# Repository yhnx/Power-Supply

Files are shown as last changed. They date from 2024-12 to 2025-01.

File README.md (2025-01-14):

# Power-Supply
A repository containing the Schematics, Presentations and 3D models which were used to design a Variable Voltage Power Supply which was built for the module EN 2091 Laboratory Practice and Projects

### **Documentation**
- [`Project_Proposal.pdf`](./DM_27/Project_Proposal.pdf): Formal proposal document for the project.
- [`Presentation_27.pptx`](./DM_27/Presentation_27.pptx): Project presentation slides.
- [`Project_report_27.pdf`](./DM_27/Project_report_27.pdf): Comprehensive project report.
  
### **DM_27**
Contains project-related files and resources.

- **Datasheets/**
  - [`BR5010 rectifier.pdf`](./DM_27/Datasheets/BR5010%20rectifier.pdf): Datasheet for the BR5010 bridge rectifier.
  - [`LD1085 (1).pdf`](./DM_27/Datasheets/LD1085%20(1).pdf): Datasheet for the LD1085 low-dropout regulator.
  - [`The TIP142G is a Darlington transistor.pdf`](./DM_27/Datasheets/The%20TIP142G%20is%20a%20Darlington%20transistor.pdf): Datasheet for the TIP142G transistor.
  - [`lm338 adjustable regulator.pdf`](./DM_27/Datasheets/lm338%20adjustable%20regulator.pdf): Datasheet for the LM338 adjustable voltage regulator.
  - [`power transformer datasheet.pdf`](./DM_27/Datasheets/power%20transformer%20datasheet.pdf): Datasheet for the power transformer used.
  - [`voltage regulator.pdf`](./DM_27/Datasheets/voltage%20regulator.pdf): Additional voltage regulator datasheet.

- **Enclosure/**
  - [`Assem1.SLDASM`](./DM_27/Enclosure/Assem1.SLDASM): SolidWorks assembly file for the enclosure.
  - [`Part1.SLDPRT`](./DM_27/Enclosure/Part1.SLDPRT): SolidWorks part file for the enclosure.
  - [`TOP.SLDPRT`](./DM_27/Enclosure/TOP.SLDPRT): SolidWorks part file for the enclosure.
  - [`bottom part.DXF`](./DM_27/Enclosure/bottom%20part.DXF): DXF file for the bottom part of the enclosure.
  - [`top part.DXF`](./DM_27/Enclosure/top%20part.DXF): DXF file for the top part of the enclosure.

- [`BOM_Linear_Power_Supply.xlsx`](./DM_27/BOM_Linear_Power_Supply.xlsx): Bill of Materials for the power supply project.
- [`Gerber files.zip`](./DM_27/Gerber%20files.zip): Gerber files for PCB manufacturing.
- [`Linear power supply Schematic.asc`](./DM_27/Linear%20power%20supply%20Schematic.asc): LTspice schematic file for the linear power supply.
- [`testing.asc`](./DM_27/testing.asc): LTspice testing simulation file.

---

## Usage Instructions

1. **View Datasheets**: Explore the `Datasheets/` folder for component specifications.
2. **Enclosure Design**: Open SolidWorks or a DXF viewer to inspect the enclosure files in the `Enclosure/` folder.
3. **PCB Manufacturing**: Use the `Gerber files.zip` for PCB fabrication.
4. **Simulation**: Open `.asc` files in LTspice for schematic simulation and analysis.
5. **Documentation**: Refer to the `Presentation_27.pptx`, `Project_Proposal.pdf`, and `Project_report_27.pdf` for project insights.

---

### The team behind 
* Yehen Asuramuni ([@yhnx](https://github.com/yhnx))
* Sineth Jayawardena ([@SinethS](https://github.com/sineths))
* Oshada Nimatha ([@Oshadha-Nimantha](https://github.com/Oshadha-Nimantha))
* Agrajith Weeragoda

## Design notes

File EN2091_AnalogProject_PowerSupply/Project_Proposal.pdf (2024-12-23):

# Proposal: Variable Voltage Linear Power Supply

Team Wave Formers

August 25, 2024

Index No. | Name
220046R | Asuramuni S. Y.
220280D | Jayawardena H.D.S.S
220429U | Nimantha K.L.W.O.
220692R | Weragoda W.A.A.P.

## Introduction

This proposal presents the design and implementation of a variable voltage linear power supply. The power supply is designed to provide a regulated DC output voltage ranging from 2V to 20V, with a maximum current output of 2.5A. A low-dropout (LDO) voltage regulator is employed to ensure stable operation and efficient power conversion.

## Functionality

The proposed linear power supply functions by first converting high-voltage AC from the mains supply into a lower AC voltage via a transformer. This AC voltage is then rectified to produce DC, filtered to smooth out the waveform, and finally regulated to the desired output voltage.

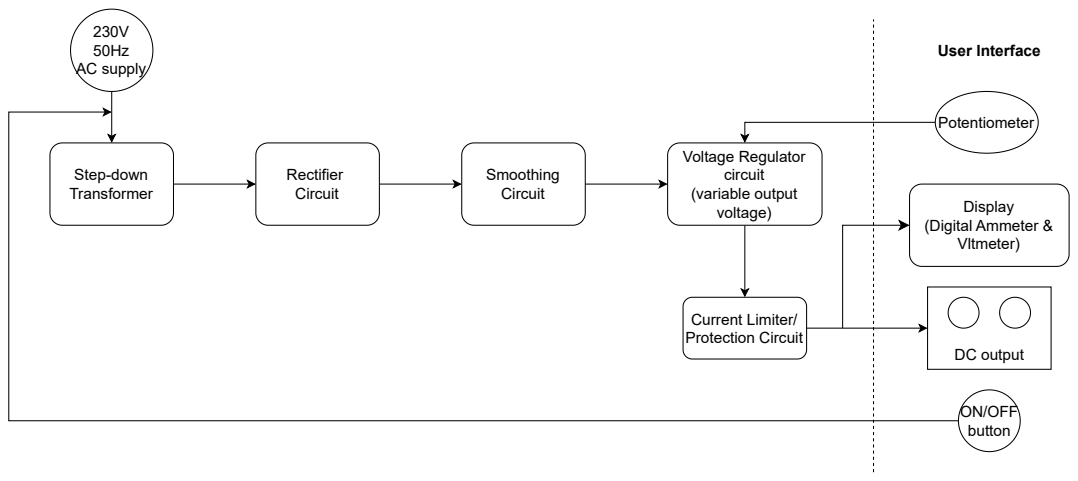
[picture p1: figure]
Rectifier Circuit; Smoothing Circuit; Voltage Regulator circuit (variable output voltage); Current Limiter/ Protection Circuit; Step-down Transformer; 230V 50Hz AC supply; User Interface; Display (Digital Ammeter & Vltmeter); DC output; ON/OFF button; Potentiometer

Figure 1: Block diagram of the power supply operation.

Transformer

The power supply utilizes a step-down transformer to reduce the mains voltage (230 VAC) to a level suitable for rectification. A transformer designed for PCB use, such as the Triad Magnetics FP16-3000, (https://www.mouser.com/datasheet/2/410/FP16_3000-781716.pdf) would be appropriate for this application.

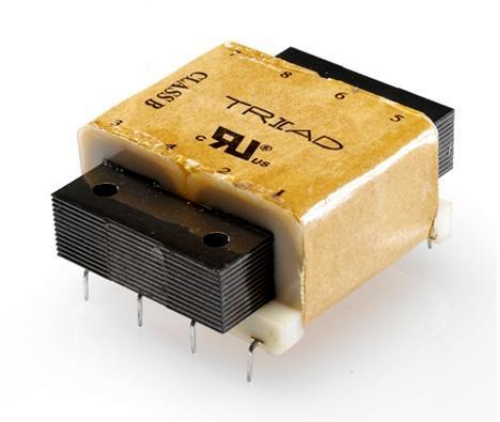
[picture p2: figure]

Figure 2: Transformer configuration for stepping down voltage.

Rectification

A full-wave bridge rectifier is employed to convert the AC voltage from the transformer into a pulsating DC voltage. The rectifier uses four diodes in a bridge configuration to ensure efficient conversion. The rectifier module should be selected based on its suitability for PCB design.

Filtering

To smooth the rectified DC voltage, a large electrolytic capacitor is used. This capacitor reduces the ripple voltage, providing a more stable DC output.

Voltage Regulation

The final stage involves regulating the smoothed DC voltage to the desired level. A low-dropout (LDO) voltage regulator, specifically the LD1085, is chosen due to its ability to handle up to 2.5A of current with minimal voltage drop.

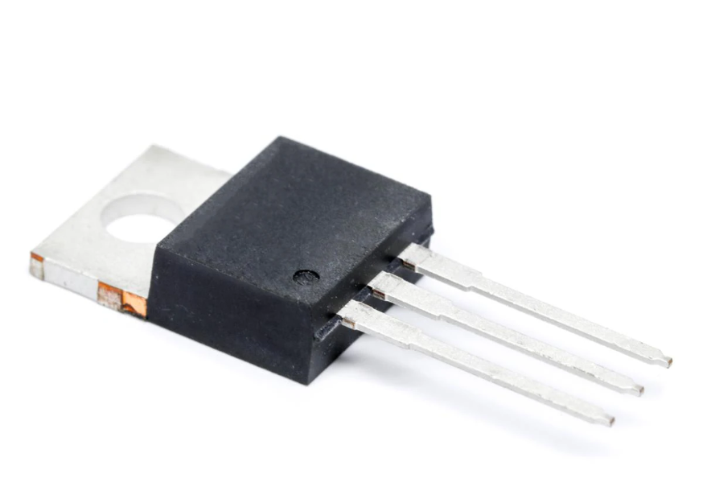
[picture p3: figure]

Figure 3: Voltage regulator LD1085.

The output voltage can be varied using a 10-turn precision potentiometer, allowing fine adjustment from 2V to 20V.

## Methodology

The construction of the power supply involves the following steps:

1. Transformer Selection: Choose a transformer that steps down the mains voltage to an appropriate level for rectification.
2. Rectifier Assembly: Construct the bridge rectifier circuit using high-efficiency diodes.
3. Filter Design: Select and connect a capacitor to smooth the rectified voltage.

4. Regulation Circuit: Implement the LD1085 voltage regulator circuit with appropriate heatsinking.
5. Enclosure Design: Assemble the components into a metal chassis for durability and heat dissipation.
6. Testing: Verify the output voltage range and load current capacity.

## Micro-Products and Their Interconnections

The power supply is divided into several micro-products:

- Transformer Module: Steps down the AC voltage.
- Rectifier Module: Converts AC to DC.
- Filter Module: Smooths the DC voltage.
- Regulation Module: Provides a stable, adjustable output voltage.

The interconnections between these modules are illustrated in the block diagram (Figure 1).

## Micro-Product Allocation

The tasks are allocated among team members as follows:

- Yehen Asuramuni: Transformer selection and rectifier assembly.
- Sineth Jayawaradhena: Enclosure design and final assembly.
- Oshadha Nimantha: Regulation circuit design and testing.
- Agrajith Pavithra: Filter design and implementation.

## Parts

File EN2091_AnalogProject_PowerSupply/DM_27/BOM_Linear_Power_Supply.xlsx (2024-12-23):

Comment | Description | Designator | Footprint | LibRef | Quantity | Manufacturer | Manufacturer Part Number
Voltmeter |  |  | JST_2_PIN | Voltmeter | 1
NPN DARL | TRANS NPN DARL 100V 10A TO247 | B1 | TIP142 | TIP142 | 1 | STMicroelectronics | TIP142
NPN | TRANS NPN 40V 0.2A TO92-3 | B2 | 2N3904BU | 2N3904BU | 1 | ON Semiconductor / Fairchild | 2N3904BU
2200u 50V | CAP ALUM 2200UF 20% 50V RADIAL | C1, C2 | B41888C6228M000 | B41888C6228M000 | 2 | TDK EPCOS | B41888C6228M000
10u 63V | CAP ALUM 10UF 20% 50V RADIAL TH | C3 | 860020672010 | 860020672010 | 1 | Wurth Electronics | 860020672010
10n | CAP ALUM 10UF 20% 50V RADIAL TH | C4, C5 | 860020672010 | 860020672010 | 2 | Wurth Electronics | 860020672010
100u 50V | CAP ALUM 100UF 20% 50V RADIAL TH | C6 | 860040674004 | 860040674004 | 1 | Wurth Electronics | 860040674004
RECT | BRIDGE RECT 1PHASE 1KV 50A BR | D1 | BR5010-G | BR5010-G | 1 | Comchip | BR5010-G
Connector | TERMINAL BLOCK, SCREW TYPE, 5.00 | J1, J2 | TB00250002BE | TB002-500-02BE | 2 | Same Sky | TB002-500-02BE
220 R | RES 470 OHM 5% 1W AXIAL | R1 | RESISTOR | 1-1625886-8 | 1 | TE Connectivity | 1-1625886-8
0.47 R | RES 0.274 OHM 2W 1% WW AXIAL | R2, R2' | RESISTOR | RWR74SR274FRB12 | 2 | Vishay Dale | RWR74SR274FRB12
720 R | RES 640 OHM 0.1% 1W AXIAL | R3 | RESISTOR | MFP1WSBBD52-640R | 1 | Yageo | MFP1WSBBD52-640R
20K POT | POT TRIMMER 20K OHM 0.5W PC PIN TOP | R4 | 3296W-1-203LF | 3296W-1-203LF | 1 | Bourns | 3296W-1-203LF
10K | POT 10K OHM 2W WIREWOUND LINEAR | R5 | JST_3_PIN | 3590S-1-103L | 1 | Bourns | 3590S-1-103L
20K | POT TRIMMER 20K OHM 0.5W PC PIN TOP | R6, R7, R8 | 3296W-1-203LF | 3296W-1-203LF | 3 | Bourns | 3296W-1-203LF
PUSH | SWITCH PUSH SPST-NO 3A 120V | SW1 | JST_2_PIN | RP3502ARED | 1 | E-Switch | RP3502ARED
ROT | SWITCH ROTARY 4POS 2.5A 125V | SW2 | JST_5_PIN | A12405RNCQ | 1 | ITT C&K | A12405RNCQ
LT1085CT | IC REG LINEAR POS ADJ 3A TO220-3 | U1 | LT1085CT | LT1085CT | 1 | Analog Devices / Linear Technology | LT1085CT#PBF
AC 230V | Voltage Source | V1 |  | VSRC | 1
24 V | ZEN 24 V 0.5W 2% | Z1 | TZX24C-TR | TZX24C-TR | 1 | Vishay Semiconductors | TZX24C-TR

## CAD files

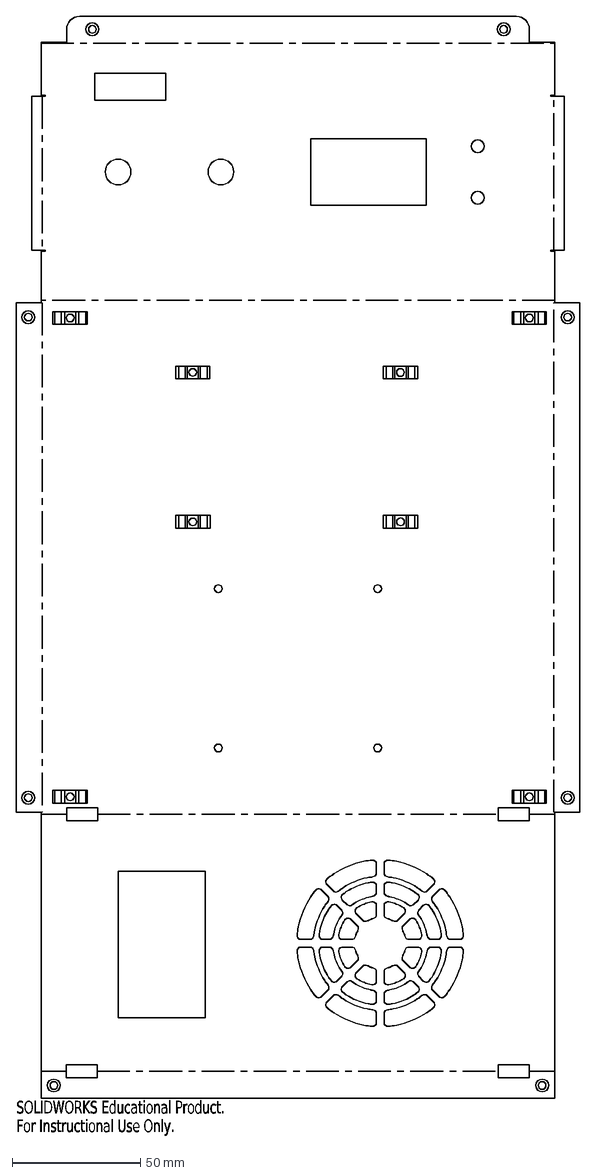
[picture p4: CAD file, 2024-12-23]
EN2091_AnalogProject_PowerSupply/DM_27/Enclosure/bottom part.DXF
SOLIDWORKS Educational Product.
For Instructional Use Only.

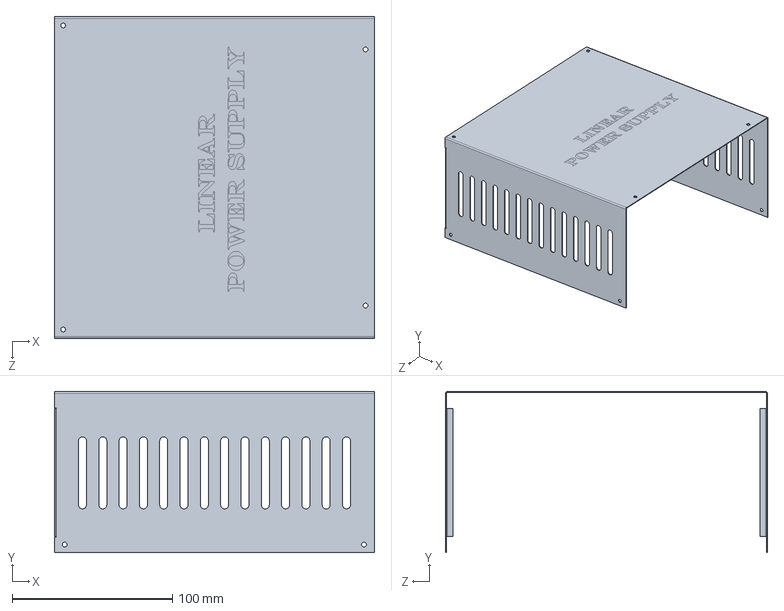
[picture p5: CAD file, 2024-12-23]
EN2091_AnalogProject_PowerSupply/DM_27/Enclosure/TOP.SLDPRT
200.0 x 100.6 x 201.2 mm

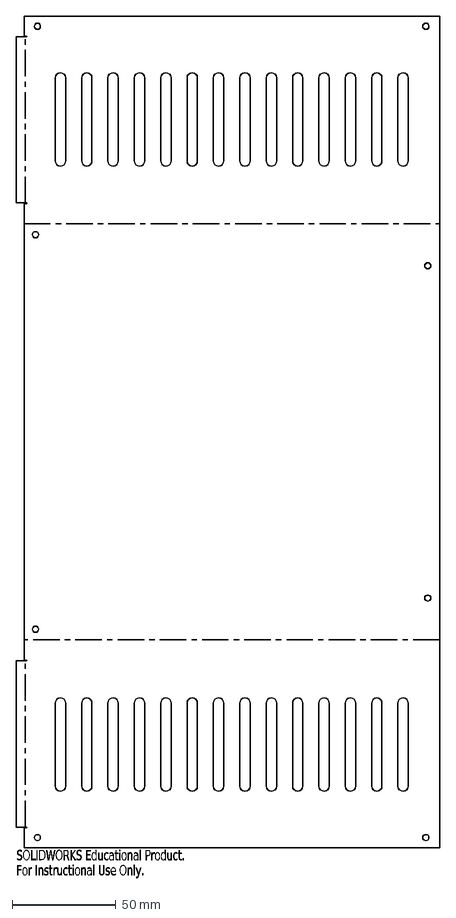
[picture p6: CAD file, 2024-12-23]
EN2091_AnalogProject_PowerSupply/DM_27/Enclosure/top part.DXF
SOLIDWORKS Educational Product.
For Instructional Use Only.

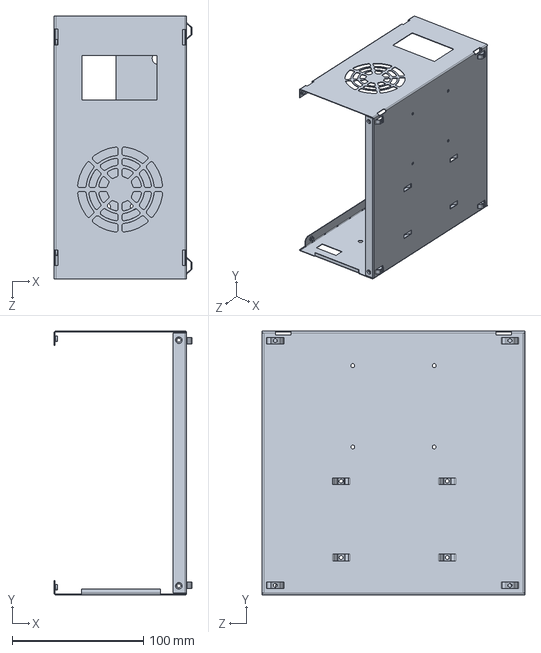
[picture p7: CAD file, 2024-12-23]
EN2091_AnalogProject_PowerSupply/DM_27/Enclosure/Part1.SLDPRT
105.0 x 201.0 x 200.0 mm

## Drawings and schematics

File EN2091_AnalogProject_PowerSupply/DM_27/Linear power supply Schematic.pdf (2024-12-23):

# Variable Voltage Linear Power Supply By Wave Formers

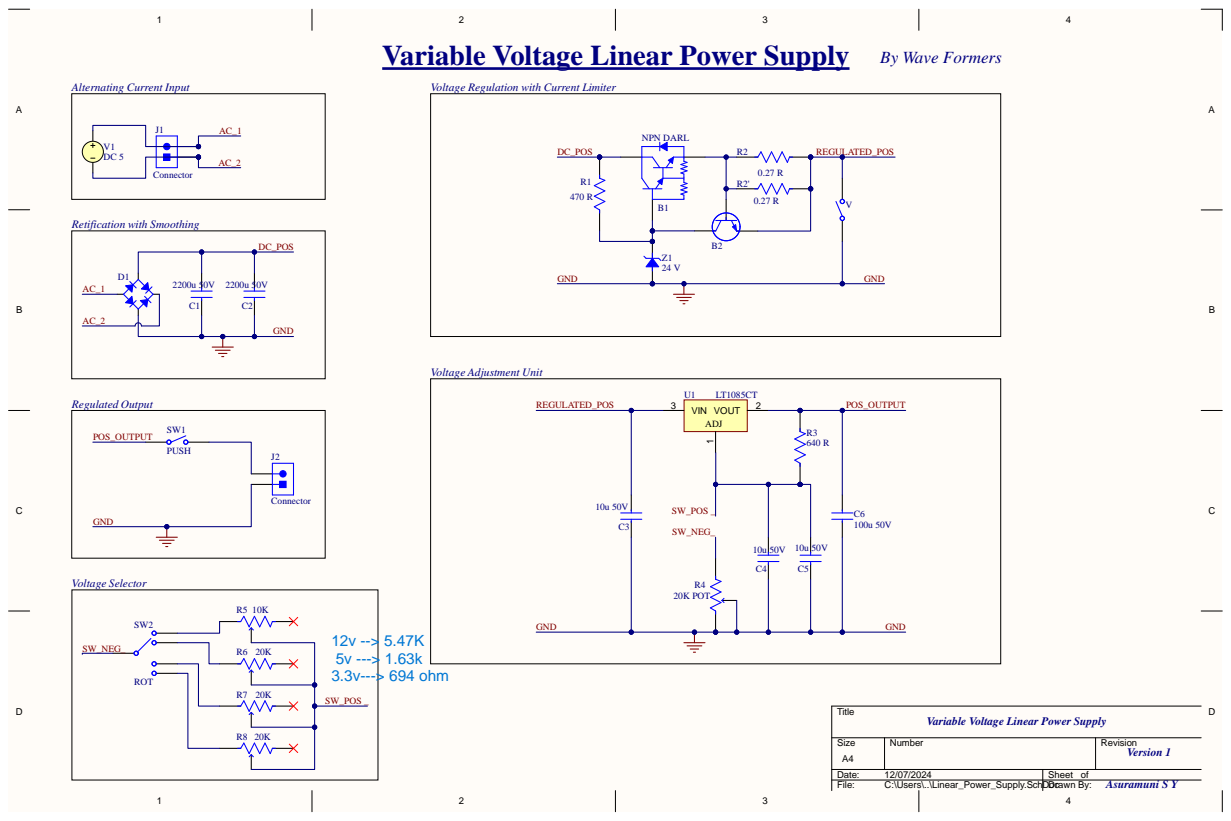
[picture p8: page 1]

Voltage Regulation with Current Limiter

Variable Voltage Linear Power Supply
